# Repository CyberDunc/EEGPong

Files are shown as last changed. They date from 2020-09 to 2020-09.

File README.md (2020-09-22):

# EEGPong
Arduino and Visual studio code necessary to play EEG Pong
Arduino zero code takes input through Analog0 input pin and communicates with computer over usb through program pin
Visual studio code needs opengl and several other libraries: glad , glfw3 , fftw3 , stdio , stdlib . 
The Visual studio code should be started after the Arduino is running
I used Ag/AgCl sintered electrodes and elecectrode gel, however an inexpensive alternative are gold electrodes, four are preffered but it can be used with 3 if you leave one of the biases unconnected. Aloe vera is a possible substitute for eeg gel, however you only need a small amount of gel and it is relatively cheap. 
The board designs were done in Eagle and assembled in house at my university, however PCBworld is my preffered manufacturer otherwise.

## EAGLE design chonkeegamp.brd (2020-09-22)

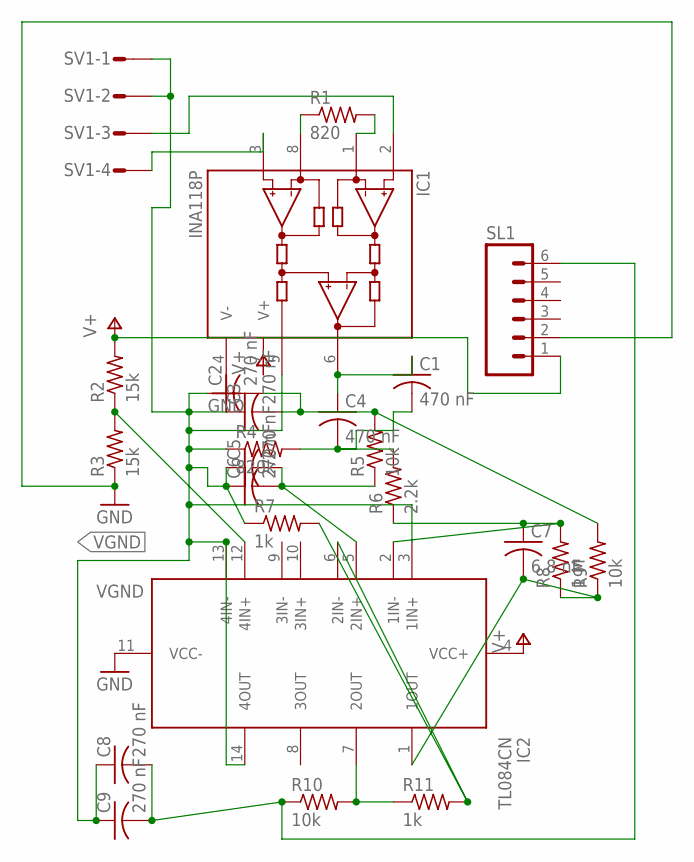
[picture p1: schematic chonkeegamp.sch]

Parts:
C1, C4: 470 nF; C050-024X044; MPN BFC237390043
C2, C3, C5, C6, C8, C9: 270 nF; C050-024X044; MPN BFC237390132
C7: 6.8 nF; C050-024X044; MPN C315C682K1R5TA
IC1: INA118P; DIL08
IC2: TL084CN; DIP794W53P254L1930H508Q14N; MPN TL084CN
R1: 820; 0207/7; MPN MCF 0.5W 820R
R2, R3: 15k; 0207/7; MPN MCF 1W 15K
R4: 820k; 0207/7; MPN MCF 0.25W 820K
R5, R9, R10: 10k; 0207/7; MPN MCCFR0W4J0103A50
R6: 2.2k; 0207/7; MPN MCF 0.5W 2K2
R7, R11: 1k; 0207/7; MPN MCCFR0S2J0102A20
R8: 1 M; 0207/7; MPN MCF 0.5W 1M
SL1: M06; 06P
SV1: L04P

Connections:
GND: IC1.4 (V-), IC2.11 (VCC-), R3.1, SL1.2
unnamed: C1.1, C4.1, IC1.6 (OUT)
unnamed: C1.2, C4.2, R4.2, R6.2
unnamed: C7.1, IC2.2 (1IN-), R6.1, R8.2
unnamed: C7.2, IC2.1 (1OUT), R8.1, R9.1
unnamed: C2.2, C3.2, R5.2, R9.2
unnamed: C5.2, C6.2, IC2.5 (2IN+), R5.1
unnamed: IC1.3 (+IN), SV1.4
unnamed: IC2.6 (2IN-), R7.2, R11.2
unnamed: IC2.7 (2OUT), R10.2, R11.1
unnamed: C8.2, C9.2, R10.1, SL1.6
unnamed: IC2.12 (4IN+), R2.1, R3.2
unnamed: IC1.2 (-IN), SV1.3
unnamed: IC1.1 (RG), R1.2
unnamed: IC1.8 (RG), R1.1
V+: IC1.7 (V+), IC2.4 (VCC+), R2.2, SL1.1
VGND: C2.1, C3.1, C5.1, C6.1, C8.1, C9.1, IC1.5 (REF), IC2.3 (1IN+), IC2.13 (4IN-), IC2.14 (4OUT), R4.1, R7.1, SV1.1, SV1.2

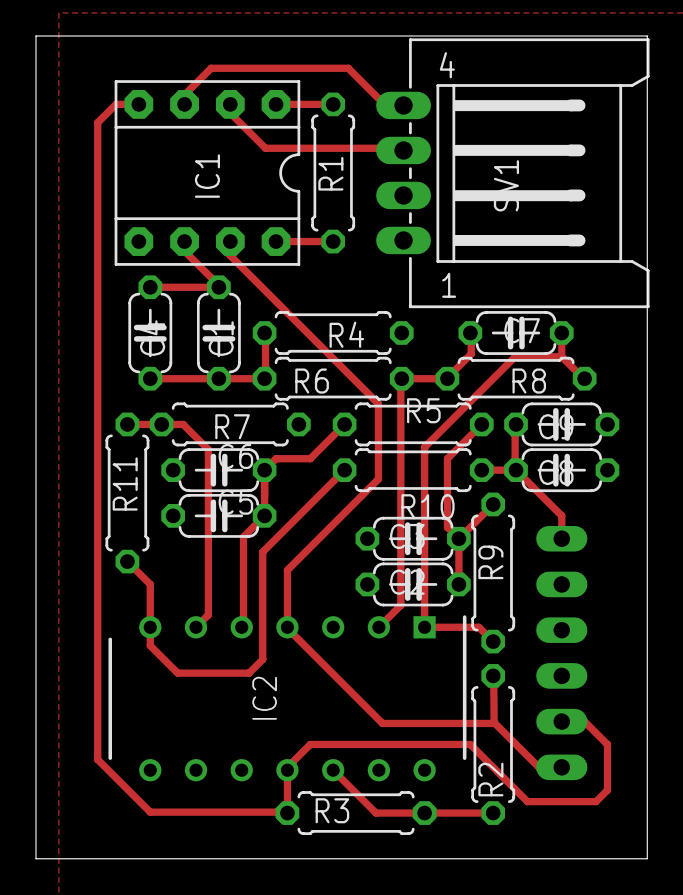
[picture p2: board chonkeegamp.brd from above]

Board: 2 copper layers, 34.0 x 45.7 mm, 24 parts (1 on the bottom side), 17 nets.

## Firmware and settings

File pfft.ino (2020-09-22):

#include <Adafruit_ZeroFFT.h>
#include <arm_common_tables.h>

#include "arduinoFFT.h"

arduinoFFT FFT = arduinoFFT(); /* Create FFT object */
/*
These values can be changed in order to evaluate the functions
*/
#define CHANNEL A0
const double res = 7, scale = 10;
const uint16_t samples = 32; //This value MUST ALWAYS be a power of 2
const double samplingFrequency =  res*samples;//Hz, must be less than 10000 due to ADC
double avesum = 0, out;
unsigned int sampling_period_us;
unsigned long microseconds;
int t = 0;
/*
These are the input and output vectors
Input vectors receive computed results from FFT
*/
double f = 10.5;
double sense = .00000001;
int16_t vReal[samples];
double vImag[samples];
double vdoub[samples];
 const int num = 10;
double vpast[num];
int32_t avg;
double ave, span = 0, gap = 0;
bool start = true;
#define SCL_INDEX 0x00
#define SCL_TIME 0x01
#define SCL_FREQUENCY 0x02
#define SCL_PLOT 0x03

void setup()
{
  sampling_period_us = round(1000000*(1.0/samplingFrequency));
  Serial.begin(115200);
}

void loop()
{
  /*SAMPLING*/
  microseconds = micros();
  for(int i=0; i<samples; i++)
  {
      vReal[i] = analogRead(CHANNEL);
      //Serial.println(vReal[i]);
      avg += vReal[i];
      if((abs((vReal[i]-vReal[i-1]))) > (sense))span = micros()-gap;// alter this to be minus average insteadof minus last?
      vImag[i] = 0;
      while(micros() - microseconds < sampling_period_us){
        //empty loop
      }
      microseconds += sampling_period_us;
  } 

  
  avg = avg/samples;
  for(int i=0; i<samples; i++) vReal[i] = (vReal[i] - avg) * 64;
    
  
  ZeroFFT(vReal, samples);
  /*  if(start = true){
       for(int i = 1; i<num; i++)vpast[i] = vReal[2]*scale/samples;
    start = false; 
  }*/
  avesum = 0;
out = vReal[2];
for(int i = 0; i<num; i++) avesum += vpast[i];
  ave = ((out*scale/samples + avesum)/((num+1)));
  //ave = round(ave);

  Serial.print(50*ave);
  Serial.print(" ");
  Serial.print(span);
  Serial.println('/n');
  gap = micros();
  span = 0;
  vpast[0] = out*scale/samples;
  //for(int i = 0; i<num; i++)Serial.println(vpast[i]);
  for(int i = num-1; i>=0; i--)vpast[i] = vpast[i-1];
 

  vpast[0] = out*scale/samples;
  //for(int i = 0; i<num; i++)Serial.println(vpast[i]);
  
  delay(0); /* Repeat after delay */
}
